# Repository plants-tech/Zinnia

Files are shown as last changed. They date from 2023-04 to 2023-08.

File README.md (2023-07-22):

# ZinniaGCC

fork of a fork of phob 2.x (Phob 2.x Official -> PhloraGCC -> ZinniaGCC)

RIP Jack Plants 

## Changes

* USB D+/D- Pad Alignment with [Model U GCC v2](https://github.com/plants-tech/Model-U-GCC-V2)
* Left Z implementation via its own pin; GPIO12
* Start Pad edit; now in style of D-Pad 
* B3f tactile switch thru-holes on ABXY pads
* Omron D2LS alignment thru-holes on ABXY pads (experimental)
* Revision of both Analog and C-Stick footprints; removal of t1/t2 thru-holes, conversion of t3 screw-holes from copper-lined pads to non-conductive thru-holes (screws work more effectively, stickbox "wobble" eliminated slightly)

## Images

### Front
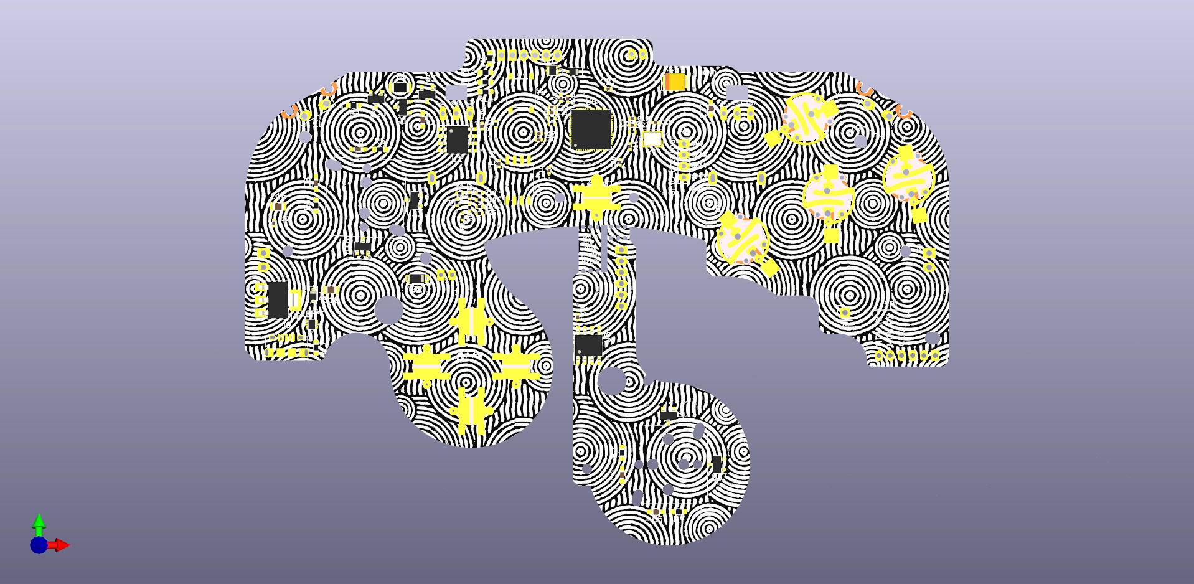
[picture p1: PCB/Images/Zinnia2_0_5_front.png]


### Back
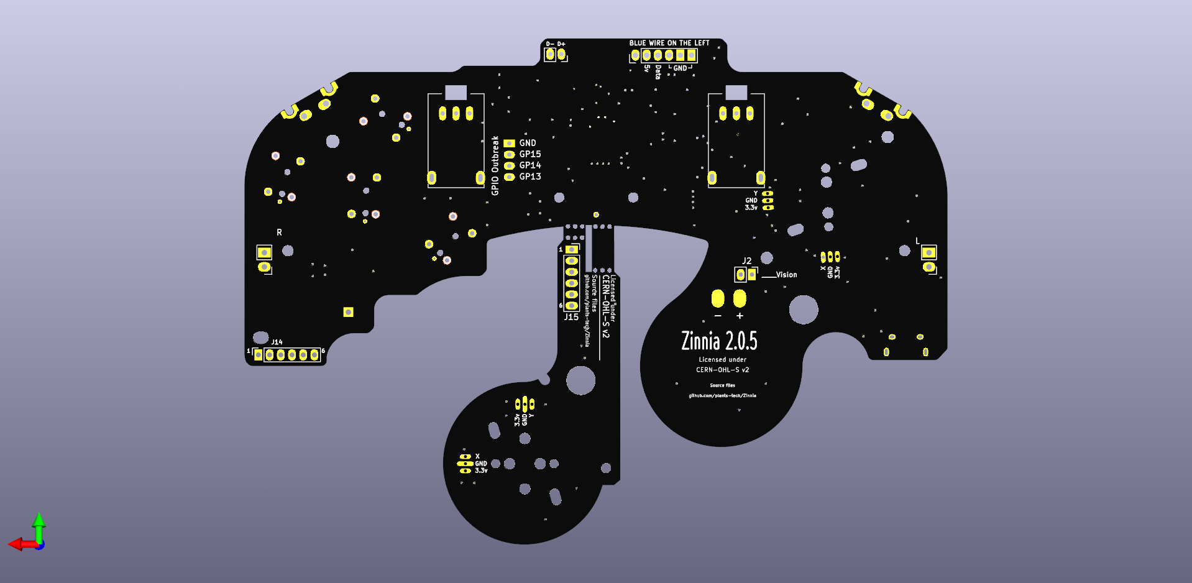
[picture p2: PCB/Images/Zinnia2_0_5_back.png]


## License

[CERN_OHL_S_v2](https://ohwr.org/cern_ohl_s_v2.txt)

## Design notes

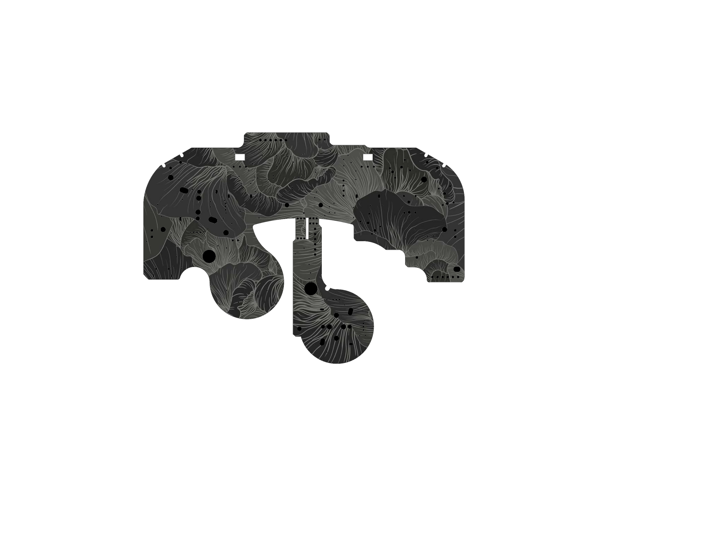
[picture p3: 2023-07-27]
PCB/Images/flower.png

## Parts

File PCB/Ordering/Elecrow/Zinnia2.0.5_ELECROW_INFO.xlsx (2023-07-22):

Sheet: PCB Specification
Your PCB Specification
PCB Quantity | 5pcs
Layer | 2layer
PCB Thickness | 1.6mm
Dimensions | 126mm*90.5mm
Castellated Hole | No
PCB Color | Black
Surface Finish | Immersion Gold
Copper Weight | 1oz
Text Color | White
Different Design | 2
Please find more PCB information on our on-line PCB ordering Page
https://www.elecrow.com/pcb-manufacturing.html

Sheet: BOM
PhobGCC v2.0.5
# | Reference | QTY | Value | Package | Manufacturer Part number | Description | SMD | THT | Original | Elecrow PN | Note
1 | R20, R21 | 2 | 27Ω | 0402 |  | Resistor | 4 |  | N
2 | R11, R12 | 2 | 100Ω | 0603 |  | Resistor | 4 |  | N
3 | R1, R2, R7, R8, R9 | 5 | 180Ω | 0402 |  | Resistor | 10 |  | N
4 | R10, R19, R24, R25 | 4 | 316Ω | 0402 |  | Resistor | 8 |  | N
5 | R16, R18 | 2 | 1kΩ | 0402 |  | Resistor | 4 |  | N
6 | R3, R4, R5, R6 | 4 | 2kΩ | 0603 |  | Resistor | 8 |  | N
7 | R13, R14, R15 | 3 | 10kΩ | 0603 |  | Resistor | 6 |  | N
8 | R17 | 1 | 100kΩ | 0603 |  | Resistor | 2 |  | N
9 | C1 | 1 | 47uF | CASE-B-3528 | CA45-B-16V-47uF-K | Capacitor | 2 |  | Y
10 | C14, C15 | 2 | 27pF | 0402 |  | Capacitor | 4 |  | N
11 | C3, C4, C5, C6, C7, C8 | 6 | 47nF | 0603 |  | Capacitor | 12 |  | N
12 | C17, C19, C20, C22, C24, C25, C26, C27, C28, C29, C30, C31, C32 | 13 | 100nF | 0402 |  | Capacitor | 26 |  | N
13 | C21, C23 | 2 | 1uF | 0402 |  | Capacitor | 4 |  | N
14 | C16, C18 | 2 | 10uF | 0805 |  | Capacitor | 4 |  | N
15 | U1, U3 | 2 |  | SOP-8 | MCP3202-CI/SN | ADC | 16 |  | Y
16 | U4, U9, U10, U11 | 4 |  | SOT-23 | DRV5055A2xDBZxQ1 | Hall Sensor | 12 |  | Y
17 | U6 | 1 |  | SOT-223-3 | AMS1117-3.3 | Voltage Regulator | 4 |  | Y
18 | U7 | 1 |  | SOIC-8-208mil | W25Q128JVSIQ | 128Mb Flash | 8 |  | Y
19 | U8 | 1 |  | LQFN-56(7x7) | RP2040 | MCU | 57 |  | Y
20 | U12, U13 | 2 |  | SOT-666-6 | USBLC6-2P6 | ESD Protection Chip | 12 |  | Y
21 | D1, D5 | 2 |  | SOD-323 | CUS10S30,H3F | Schottky Barrier Diode | 4 |  | Y
22 | D2 | 1 |  | SOD-123 | B5819W SL | Schottky Barrier Diode | 2 |  | Y
23 | Q1, Q3 | 2 |  | SOT-23-3L | AO3400A | N-Channel MOSFET | 6 |  | Y
24 | Q2 | 1 |  | SOT-23-3L | AO3401A | P-Channel MOSFET | 3 |  | Y
25 | S1 | 1 |  | SMD | TS-1187A-B-A-B | Golden Round Button | 4 |  | Y
26 | Y1 | 1 |  | SMD3225-4P | TAXM12M4RKDCDT2T | SMD Crystal Oscillator | 4 |  | Y
27 | F1 | 1 |  | 1206 | nSMD020-30V | Resettable Fuse | 2 |  | Y
28 | J8 | 1 |  | SMD | 10118194-0001LF | USB Micro | 9 |  | Y
29
30
 |  |  |  |  |  | total： | 241 | 0
 | Declare：
 | 1、If the component should be original like Digi-key or Mouser，the component must have complete Manufacture part number

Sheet: Position File
Designator |  | Footprint | Center-X(mm) | Center-Y(mm) | Rotation | Layer
C1 | 0.047u | C_0603_HandSoldering | 124.968 | 30.48 | 0 | top
C3 | 0.047u | C_0603_HandSoldering | 131.318 | -35.24 | 90 | top
C4 | 0.047u | C_0603_HandSoldering | 115.518 | -100.46 | -90 | top
C5 | 0.047u | C_0603_HandSoldering | 121.568 | -107.01 | 180 | top
C6 | 0.047u | C_0603_HandSoldering | 68.5 | -42.5 | 180 | top
C7 | 0.047u | C_0603_HandSoldering | 80 | -37.25 | -90 | top
C8 | 0.047u | C_0603_HandSoldering | 61 | -48.5 | 90 | top
C14 | 27p | C_0402_1005Metric | 116.9 | -42 | -90 | top
C15 | 27p | C_0402_1005Metric | 121.412 | -37.719 | 0 | top
C16 | 10u | C_0805_2012Metric | 54.295 | -52.705 | 0 | top
C17 | 100n | C_0402_1005Metric | 100.7 | -39.7 | 180 | top
C18 | 10u | C_0805_2012Metric | 63.67 | -67.54 | 0 | top
C19 | 100n | C_0402_1005Metric | 117.3 | -37 | 0 | top
C20 | 100n | C_0402_1005Metric | 100.7 | -40.8 | 180 | top
C21 | 1u | C_0402_1005Metric | 103 | -36 | 180 | top
C22 | 100n | C_0402_1005Metric | 117.3 | -38.2 | 0 | top
C23 | 1u | C_0402_1005Metric | 103 | -35 | 180 | top
C24 | 100n | C_0402_1005Metric | 102.5 | -46.25 | -90 | top
C25 | 100n | C_0402_1005Metric | 115.1 | -44.82 | -90 | top
C26 | 100n | C_0402_1005Metric | 105.8 | -33.528 | 90 | top
C27 | 100n | C_0402_1005Metric | 113.03 | -31.75 | 0 | top
C28 | 100n | C_0402_1005Metric | 104.6 | -33.401 | 90 | top
C29 | 100n | C_0402_1005Metric | 53.5 | -55.626 | -90 | top
C30 | 100n | C_0402_1005Metric | 90.551 | -38.354 | 90 | top
C31 | 100n | C_0402_1005Metric | 93.599 | -45.085 | -90 | top
C32 | 100n | C_0402_1005Metric | 107.5944 | -72.3646 | 90 | top
D1 | CUS10S30,H3F | D_SOD-323 | 60.46 | -68.4925 | -90 | top
D2 | M7C | D_SOD-123 | 79 | -65.51 | 180 | top
D5 | CUS10S30,H3F | D_SOD-323 | 106.934 | -28.702 | 180 | top
F1 | Fuse | Fuse_1206_3216Metric | 76 | -31.5 | 0 | top
J8 | USB_B_Micro | USB_Micro-B_Amphenol_10118194_Horizontal | 55.74 | -77.39 | 0 | top
Q1 | Q_NMOS_GSD | SOT-23 | 76.5 | -35 | 180 | top
Q2 | Q_PMOS_GDS | SOT-23 | 71.7 | -33.6 | -90 | top
Q3 | Q_NMOS_GSD | SOT-23 | 80.79 | -32.75 | -90 | top
R1 | 180 | R_0402_1005Metric | 86.106 | -52 | -90 | top
R2 | 180 | R_0402_1005Metric | 86.606 | -50.3 | 180 | top
R3 | 2k | R_0603_1608Metric_Pad0.98x0.95mm_HandSolder | 115.518 | -96.51 | 90 | top
R4 | 2k | R_0603_1608Metric_Pad0.98x0.95mm_HandSolder | 125.6055 | -107.01 | 0 | top
R5 | 2k | R_0603_1608Metric_Pad0.98x0.95mm_HandSolder | 72.4125 | -42.5 | 0 | top
R6 | 2k | R_0603_1608Metric_Pad0.98x0.95mm_HandSolder | 61 | -52.5 | -90 | top
R7 | 180 | R_0402_1005Metric | 88.356 | -50.8 | 90 | top
R8 | 180 | R_0402_1005Metric | 88.356 | -52.9 | 90 | top
R9 | 180 | R_0402_1005Metric | 87.056 | -54.5 | 90 | top
R10 | 316 | R_0402_1005Metric | 90.106 | -50.3 | 0 | top
R11 | 100R | R_0603_1608Metric_Pad0.98x0.95mm_HandSolder | 91.19 | -28.83 | 180 | top
R12 | 100R | R_0603_1608Metric_Pad0.98x0.95mm_HandSolder | 91.186 | -30.53 | 180 | top
R13 | 10k | R_0603_1608Metric_Pad0.98x0.95mm_HandSolder | 67.7 | -34.7 | 180 | top
R14 | 10k | R_0603_1608Metric_Pad0.98x0.95mm_HandSolder | 91.19 | -32.23 | 0 | top
R15 | 10k | R_0603_1608Metric_Pad0.98x0.95mm_HandSolder | 91.9 | -26.3 | -90 | top
R16 | 1k | R_0402_1005Metric | 93 | -38 | 90 | top
R17 | 100k | R_0603_1608Metric_Pad0.98x0.95mm_HandSolder | 61.02 | -77.78 | 90 | top
R18 | 1k | R_0402_1005Metric | 117.3 | -39.4 | 0 | top
R19 | 316 | R_0402_1005Metric | 90.106 | -51.5 | 0 | top
R20 | 27 | R_0402_1005Metric | 103 | -38 | 0 | top
R21 | 27 | R_0402_1005Metric | 103 | -37 | 0 | top
R24 | 316 | R_0402_1005Metric | 90.106 | -52.7 | 0 | top
R25 | 316 | R_0402_1005Metric | 90.106 | -53.9 | 0 | top
S1 | BOOTSEL | SW_TS-1187A-B-A-B | 97.5 | -32.1625 | -90 | top
U1 | MCP3002 | SOIC-8_3.9x4.9mm_P1.27mm | 86.2 | -40.8 | 0 | top
U3 | MCP3002 | SOIC-8_3.9x4.9mm_P1.27mm | 109.518 | -77.41 | 90 | top
U4 | DRV5055A2xDBZxQ1 | SOT-23 | 123.716 | -89.91 | -90 | top
U6 | AMS1117-3.3 | SOT-223-3_TabPin2 | 54.26 | -69.34 | 0 | top
U7 | W25Q128JVS | SOIC-8_5.23x5.23mm_P1.27mm | 97 | -48 | 90 | top
U8 | RP2040 | RP2040-QFN-56 | 110 | -39 | 90 | top
U9 | DRV5055A2xDBZxQ1 | SOT-23 | 132.418 | -98.61 | 180 | top
U10 | DRV5055A2xDBZxQ1 | SOT-23 | 69.350935 | -59.811215 | 87 | top
U11 | DRV5055A2xDBZxQ1 | SOT-23 | 78.475 | -51.575 | 177 | top
U12 | USBLC6-2P6 | SOT-666 | 60.26 | -73.65 | 0 | top
U13 | USBLC6-2P6 | SOT-666 | 103.124 | -28.44 | 0 | top
Y1 | Crystal_GND24 | Crystal_SMD_3225-4Pin_3.2x2.5mm | 120.9 | -40.65 | 180 | top

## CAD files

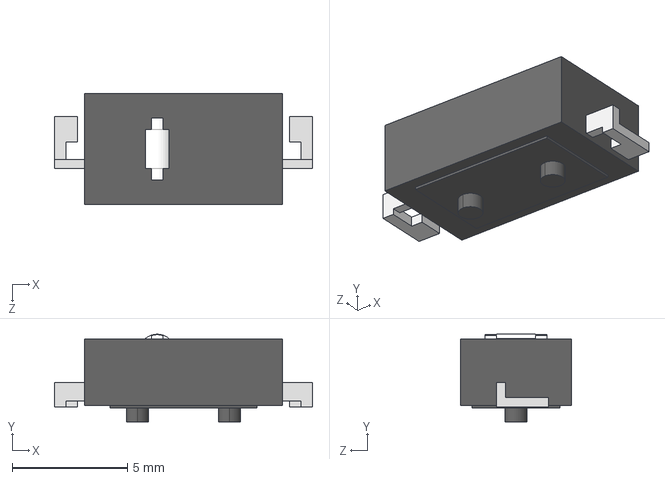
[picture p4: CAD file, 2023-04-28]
PCB/Models and Such/d2ls11.models/D2LS_11.step
11.2 x 3.80 x 4.80 mm
D2LS_11_BUTTON
D2LS_11_BASE

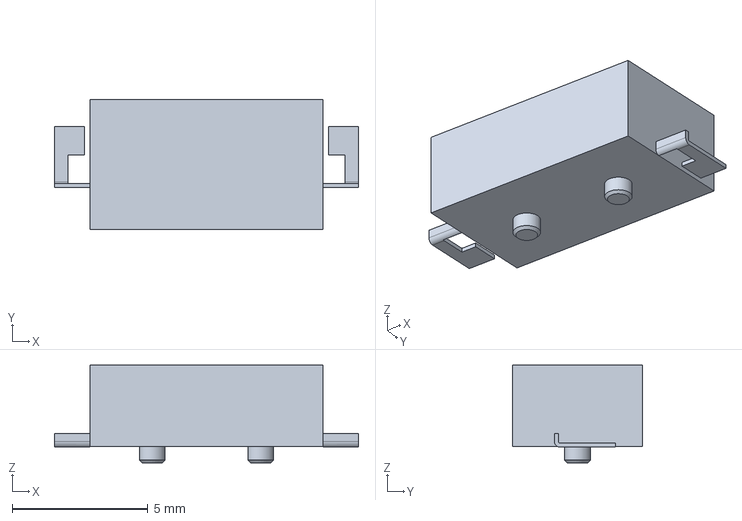
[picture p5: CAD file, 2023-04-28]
PCB/Models and Such/d2ls11.models/Omron_-_D2LS-11.step
11.2 x 4.80 x 3.60 mm

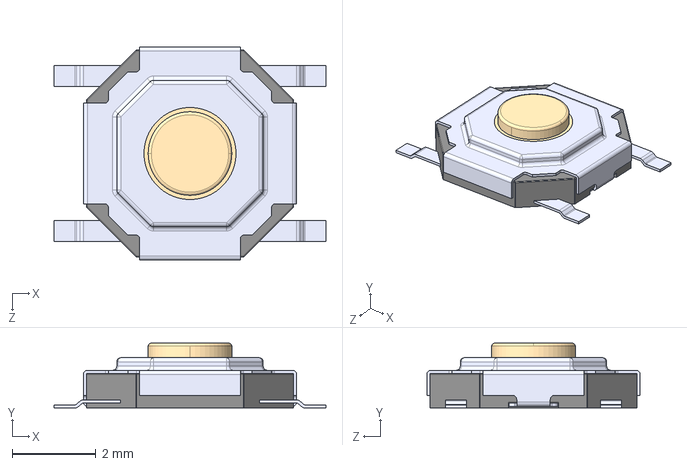
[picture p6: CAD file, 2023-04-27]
PCB/Models and Such/TS-1187A-B-A-B--3DModel-STEP-56544.STEP
6.50 x 1.55 x 5.10 mm

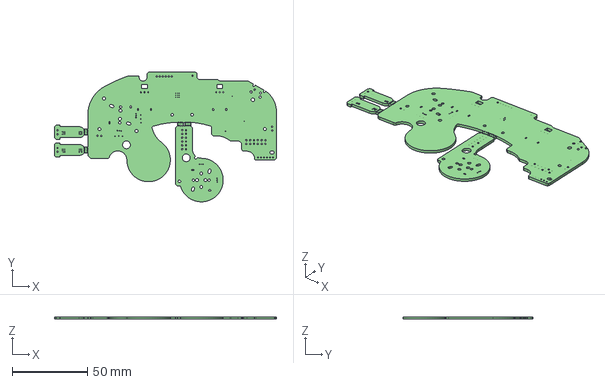
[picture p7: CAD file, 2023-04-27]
PCB/Models and Such/PhobGCC_test.step
147.6 x 86.2 x 1.60 mm

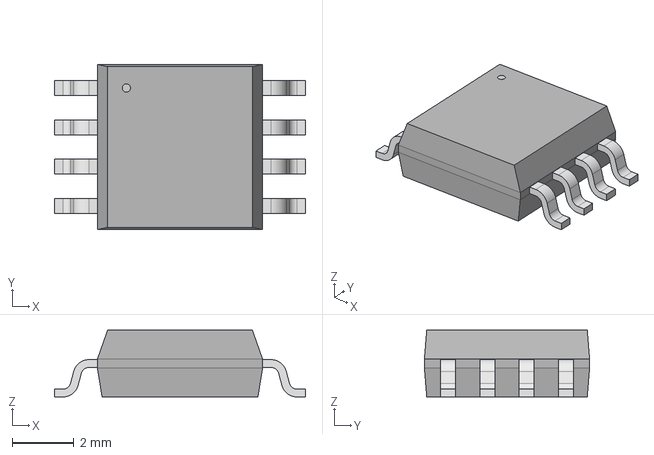
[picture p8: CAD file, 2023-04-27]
PCB/Models and Such/SOIC_128JVSIQ_WIN.step
8.10 x 5.33 x 2.16 mm

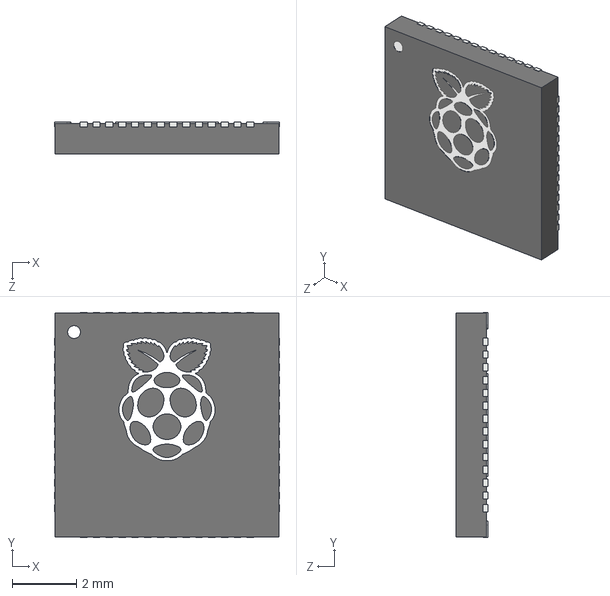
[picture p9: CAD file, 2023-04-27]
PCB/Models and Such/RP2040_QFN_PACKAGE.STEP
7.02 x 7.02 x 1.00 mm

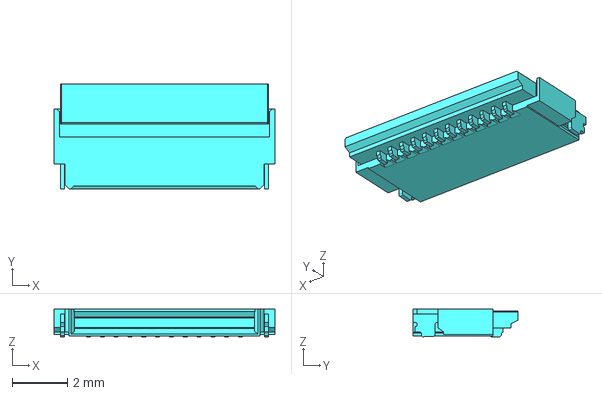
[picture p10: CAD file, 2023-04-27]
PCB/Models and Such/FH34SRJ-12S-0.5SH.stp
8.00 x 3.80 x 1.00 mm

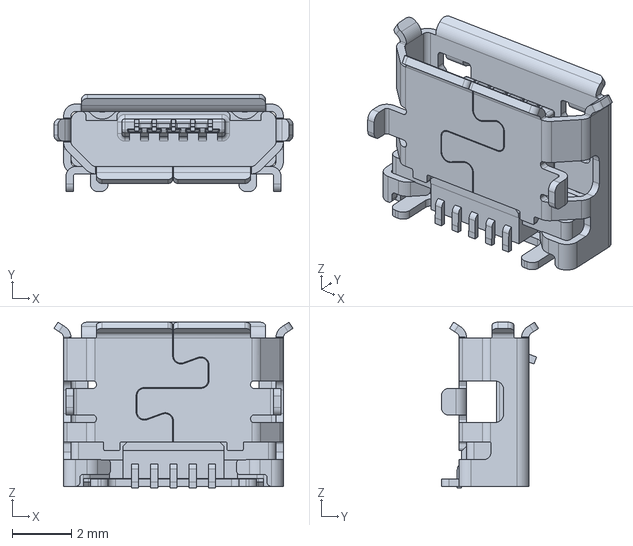
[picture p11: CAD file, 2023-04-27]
PCB/Models and Such/10118194c.stp
8.05 x 3.27 x 5.58 mm

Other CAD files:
PCB/Models and Such/10118194C.igs
PCB/Models and Such/FH34SRJ-12S-0.5SH.igs

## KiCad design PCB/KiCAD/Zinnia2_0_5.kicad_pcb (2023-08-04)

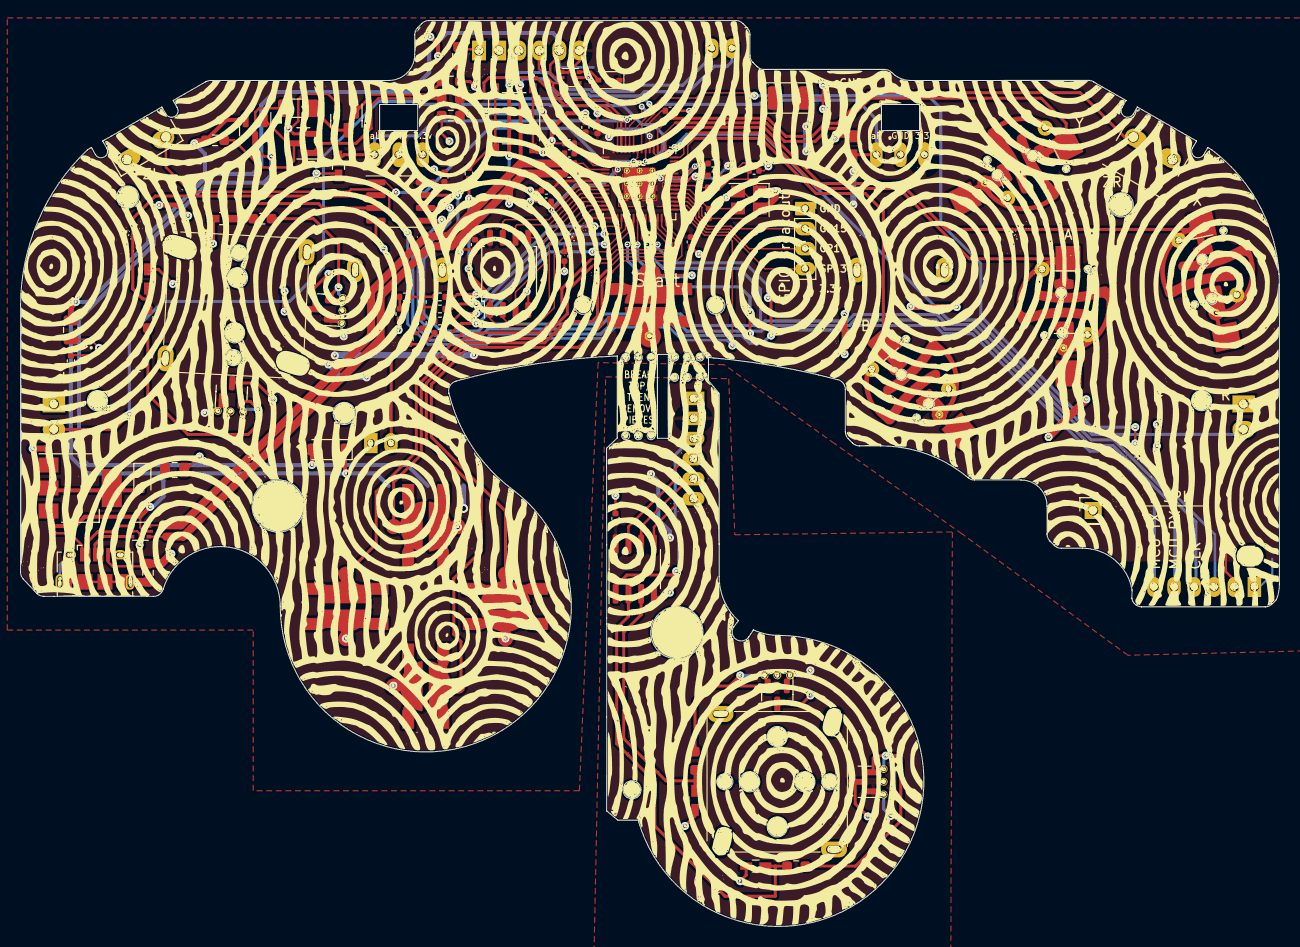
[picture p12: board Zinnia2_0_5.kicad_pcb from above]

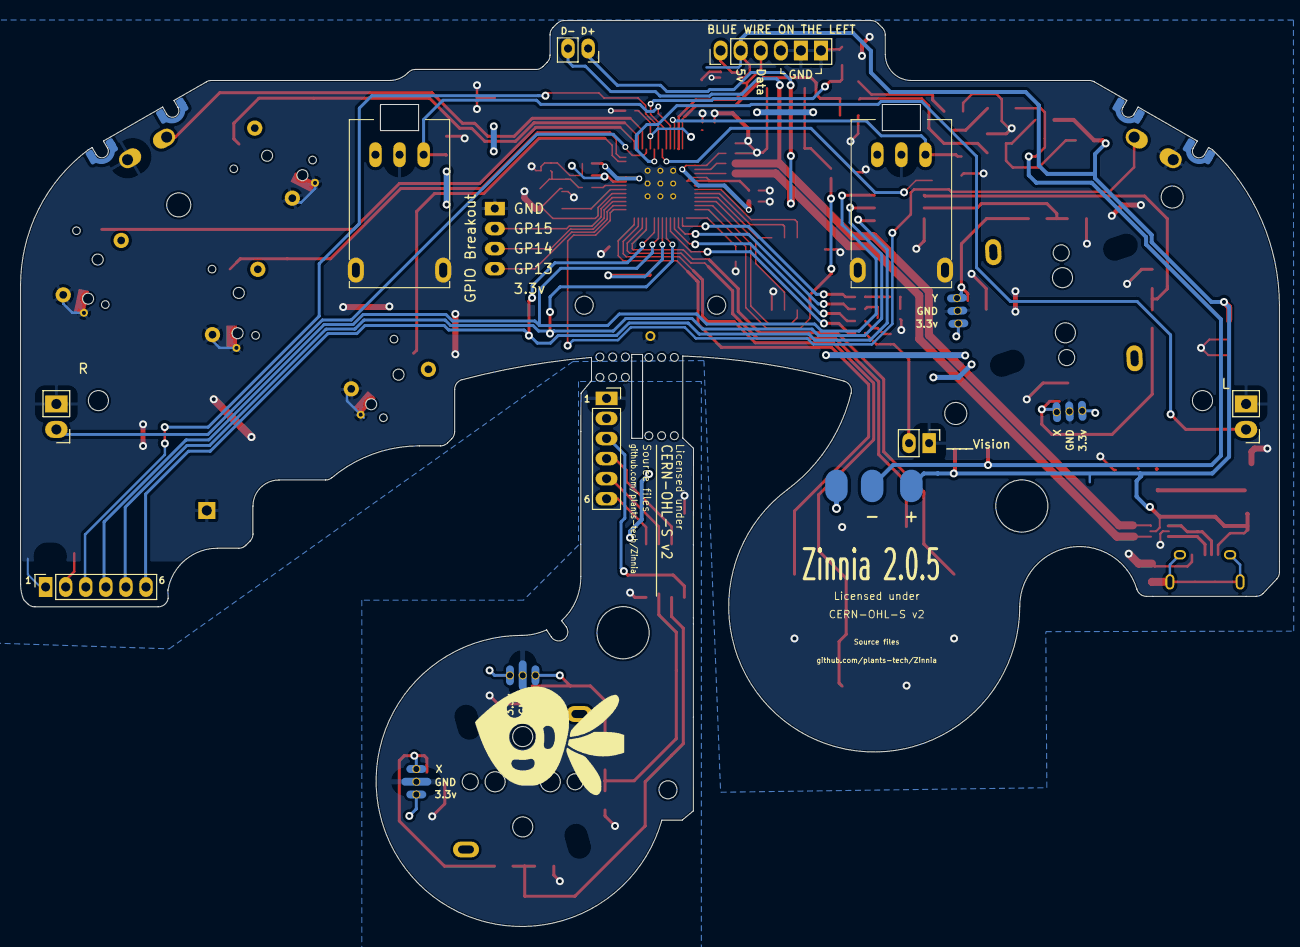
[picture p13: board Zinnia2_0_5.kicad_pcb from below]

Board: 2 copper layers, 125.4 x 90.3 mm, 110 parts (9 on the bottom side), 77 nets.

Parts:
C1: 47u; CP_EIA-3528-12_Kemet-T
C3, C4, C5, C6, C7, C8: 0.047u; C_0603_HandSoldering
C14, C15: 27p; C_0402_1005Metric
C16, C18: 10u; C_0805_2012Metric
C17, C19, C20, C22, C24, C25, C26, C27, C28, C29, C30, C31, C32: 100n; C_0402_1005Metric
C21, C23: 1u; C_0402_1005Metric
D1, D5: CUS10S30,H3F; D_SOD-323
D2: M7C; D_SOD-123
F1: Fuse; Fuse_1206_3216Metric
H1: 5.2mm; MountingHole_5.2mm
H2: Slot
H3, H4: 2mm; MountingHole_2.0mm
H5, H6: 1.8mm; MountingHole_1.8mm
H7: 2.4mm; MountingHole_2.4mm
H8, H9: 2.2mm; MountingHole_2.2mm
H10: MountingHole; MountingHole_1.8mm
H11: MountingHole; MountingHole_5.2mm
H12, H13: MountingHole; MountingHole_2.0mm
H14: MouseBite; breakaway-mousebites-double-v2-small
H15: MouseBite; breakaway-mousebites-double-v2-large
J1: Conn_01x06_Female; GCC_Header_Straight_1x06_Pitch2.00mm
J2, J11: Conn_01x02; PinHeader_1x02_P2.00mm_Vertical
J4: Conn_01x01; PinHeader_1x01_P2.54mm_Vertical
J5: Rumble; rumble_pins
J6: PinSocket_1x04_P2.00mm_Vertical
J9: USB_B_Micro; USB_Micro-B_Amphenol_10118194_Horizontal
J14, J15: Conn_01x06; PinSocket_1x06_P2.00mm_Vertical
Q1, Q3: Q_NMOS_GSD; SOT-23
Q2: Q_PMOS_GDS; SOT-23
R1, R2, R7, R8, R9: 180; R_0402_1005Metric
R3, R4, R5, R6: 2k; R_0603_1608Metric_Pad0.98x0.95mm_HandSolder
R10, R19, R24, R25: 316; R_0402_1005Metric
R11, R12: 100R; R_0603_1608Metric_Pad0.98x0.95mm_HandSolder
R13, R14, R15: 10k; R_0603_1608Metric_Pad0.98x0.95mm_HandSolder
R16, R18: 1k; R_0402_1005Metric
R17: 100k; R_0603_1608Metric_Pad0.98x0.95mm_HandSolder
R20, R21: 27; R_0402_1005Metric
RV1, RV2: R_POT_MountingPin; GCC_Slider
S1: BOOTSEL; SW_TS-1187A-B-A-B
SW1: A; ABXY_Contact_Omron_Switch_b3F
SW2: B; ABXY_Contact_Omron_Switch_b3F_v2
SW3: X; ABXY_Contact_Omron_Switch_b3F_v2
SW4: Y; ABXY_Contact_Omron_Switch_b3F_v2
SW5: Start; Dpad_Contact_TL3315NF_2
SW6: L; Pin_Header_Straight_1x02_Pitch2.54mm
SW7: R; Pin_Header_Straight_1x02_Pitch2.54mm
SW8: Z; Z_Switch_Edge_Omron
SW8L: ZL; Z_Switch_Edge_Omron
SW9: Dleft; Dpad_Contact_TL3315NF_2
SW10: Dup; Dpad_Contact_TL3315NF_2
SW11: Dright; Dpad_Contact_TL3315NF_2
SW12: Ddown; Dpad_Contact_TL3315NF_2
U1, U3: MCP3002; SOIC-8_3.9x4.9mm_P1.27mm
U2: Stickbox_Assembly_Main; GCC_Stickbox_Hall_Only
U4, U9, U10, U11: DRV5055A2xDBZxQ1; SOT-23
U5: Stickbox_Assembly_CStick; GCC_Stickbox_Hall_Only
U6: AMS1117-3.3; SOT-223-3_TabPin2
U7: W25Q128JVS; SOIC-8_5.23x5.23mm_P1.27mm
U8: RP2040; RP2040-QFN-56
U12, U13: USBLC6-2P6; SOT-666
Y1: Crystal_GND24; Crystal_SMD_3225-4Pin_3.2x2.5mm

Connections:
+1V1: C19.1, C20.1, C21.1, U8.23 (DVDD), U8.45 (VREG_VOUT), U8.50 (DVDD)
+3V3: C1.1, C17.1, C18.1, C22.1, C23.1, C24.1, C25.1, C26.1, C27.1, C28.1, C29.1, C30.1, C31.1, D1.1 (K), D5.1 (K), J1.1, J14.2, RV1.1 (V+), RV2.1 (V+), U1.8 (VDD/VREF), U2.1 (H1XV), U2.4 (H1YV), U7.8 (VCC), U8.1 (IOVDD), U8.10 (IOVDD), U8.22 (IOVDD), U8.33 (IOVDD), U8.42 (IOVDD), U8.43 (ADC_AVDD), U8.44 (VREG_IN), U8.48 (USB_VDD), U8.49 (IOVDD), U10.1 (VCC), U11.1 (VCC), U13.4
+5V: C16.1, D2.1 (K), J1.2, J5.1, J9.1, Q2.2 (S), R13.2, U6.3 (VI), U12.5, U13.5
/A: SW1.1, U8.28 (GPIO17)
/B: SW2.1, U8.27 (GPIO16)
/Brake: R12.1, R14.2, U8.41 (GPIO29_ADC3)
/CLK: J14.4, U1.7 (CLK), U8.8 (GPIO6)
/CLK2: J15.4, U3.7 (CLK)
/CS1: U1.1 (~CS/SHDN), U8.36 (GPIO24)
/CS2: J14.3, U8.35 (GPIO23)
/CS2_2: J15.3, U3.1 (~CS/SHDN)
/C_x_filt: C5.1, R4.1, U3.2 (CH0)
/C_y_filt: C4.1, R3.1, U3.3 (CH1)
/Ddown: SW12.1, U8.13 (GPIO10)
/Din: J14.6, U1.5 (DIN), U8.9 (GPIO7)
/Din2: J15.6, U3.5 (DIN)
/Dleft: SW9.1, U8.11 (GPIO8)
/Dout: J14.5, U1.6 (DOUT), U8.6 (GPIO4)
/Dout2: J15.5, U3.6 (DOUT)
/Dright: SW11.1, U8.14 (GPIO11)
/Dup: SW10.1, U8.12 (GPIO9)
/GCC_DATA: J1.3, U8.40 (GPIO28_ADC2), U13.6
/GND_C: C4.2, C5.2, C32.2, J15.1, U3.4 (VSS), U4.3 (GND), U5.2 (H1XG), U5.5 (H1YG), U9.3 (GND)
/GPIO13: J6.4, U8.16 (GPIO13)
/GPIO14: J6.3, U8.17 (GPIO14)
/GPIO15: J6.2, U8.18 (GPIO15)
/H1XS: R6.2, U2.3 (H1XS), U10.2 (OUT)
/H1YS: R5.2, U2.6 (H1YS), U11.2 (OUT)
/H2XS: R4.2, U5.3 (H1XS), U9.2 (OUT)
/H2YS: R3.2, U4.2 (OUT), U5.6 (H1YS)
/L: SW6.1, U8.34 (GPIO22)
/Ladder1: R10.2, U8.2 (GPIO0)
/Ladder2: R19.2, U8.3 (GPIO1)
/Ladder3: R24.2, U8.4 (GPIO2)
/Ladder4: R25.2, U8.5 (GPIO3)
/Lanalog: C7.1, RV1.3 (Signal), U8.39 (GPIO27_ADC1)
/LeftZ: SW8L.2, U8.15 (GPIO12)
/QSPI_SCLK: U7.6 (CLK), U8.52 (QSPI_SCLK)
/QSPI_SD0: U7.5 (DI(IO0)), U8.53 (QSPI_SD0)
/QSPI_SD1: U7.2 (DO(IO1)), U8.55 (QSPI_SD1)
/QSPI_SD2: U7.3 (IO2), U8.54 (QSPI_SD2)
/QSPI_SD3: U7.7 (IO3), U8.51 (QSPI_SD3)
/QSPI_SS: R16.1, U7.1 (~CS), U8.56 (QSPI_SS)
/R: SW7.1, U8.32 (GPIO21)
/Ranalog: C3.1, RV2.3 (Signal), U8.38 (GPIO26_ADC0)
/Rumble: R11.1, R15.2, U8.37 (GPIO25)
/Start: SW5.1, U8.7 (GPIO5)
/Stick_x_filt: C8.1, R6.1, U1.2 (CH0)
/Stick_y_filt: C6.1, R5.1, U1.3 (CH1)
/USB_D+: J11.1, R20.1, U12.4
/USB_D-: J11.2, R21.1, U12.6
/V: J2.2, R9.1, R25.1
/X: SW3.1, U8.29 (GPIO18)
/XIN: C14.1, U8.20 (XIN), Y1.3
/XOUT: R18.1, U8.21 (XOUT)
/Y: SW4.1, U8.30 (GPIO19)
/Z: SW8.1, U8.31 (GPIO20)
/~USB_BOOT: R16.2, S1.C, S1.D
GND: C1.2, C3.2, C6.2, C7.2, C8.2, C14.2, C15.2, C16.2, C17.2, C18.2, C19.2, C20.2, C21.2, C22.2, C23.2, C24.2, C25.2, C26.2, C27.2, C28.2, C29.2, C30.2, C31.2, J1.4, J1.5, J1.6, J2.1, J4.1, J6.1, J9.5, J14.1, Q1.2 (S), Q3.2 (S), R1.2, R14.1, R15.1, R17.2, RV1.2 (GND), RV2.2 (GND), S1.A, S1.B, SW1.2, SW2.2, SW3.2, SW4.2, SW5.2, SW5.3, SW6.2, SW7.2, SW8.2, SW8L.1, SW9.2, SW10.2, SW11.2, SW12.2, U1.4 (VSS), U2.2 (H1XG), U2.5 (H1YG), U6.1 (GND), U7.4 (GND), U8.19 (TESTEN), U8.57 (GND), U10.3 (GND), U11.3 (GND), U12.2, U13.2, Y1.2, Y1.4
unnamed: C15.1, R18.2, Y1.1
unnamed: D1.2 (A), U6.2 (VO)
unnamed: D2.2 (A), F1.1, J5.2, Q2.3 (D)
unnamed: D5.2 (A), U13.3
unnamed: F1.2, Q3.3 (D)
unnamed: J9.6, R17.1
unnamed: Q1.1 (G), R12.2
unnamed: Q1.3 (D), Q2.1 (G), R13.1
unnamed: Q3.1 (G), R11.2
unnamed: R1.1, R2.2
unnamed: R2.1, R7.2, R10.1
unnamed: R7.1, R8.2, R19.1
unnamed: R20.2, U8.47 (USB_DP)
unnamed: R21.2, U8.46 (USB_DM)
unnamed: R8.1, R9.2, R24.1
USB_D+_Raw: J9.3, U12.3
USB_D-_Raw: J9.2, U12.1
VCC: C32.1, J15.2, U3.8 (VDD/VREF), U4.1 (VCC), U5.1 (H1XV), U5.4 (H1YV), U9.1 (VCC)

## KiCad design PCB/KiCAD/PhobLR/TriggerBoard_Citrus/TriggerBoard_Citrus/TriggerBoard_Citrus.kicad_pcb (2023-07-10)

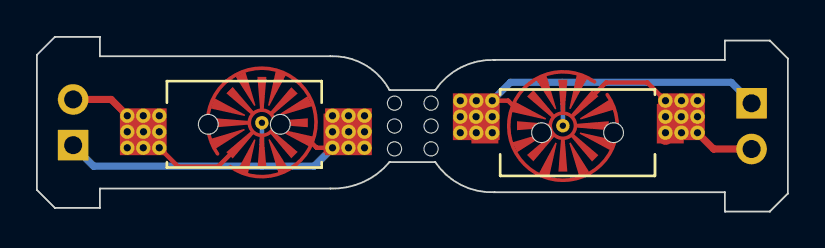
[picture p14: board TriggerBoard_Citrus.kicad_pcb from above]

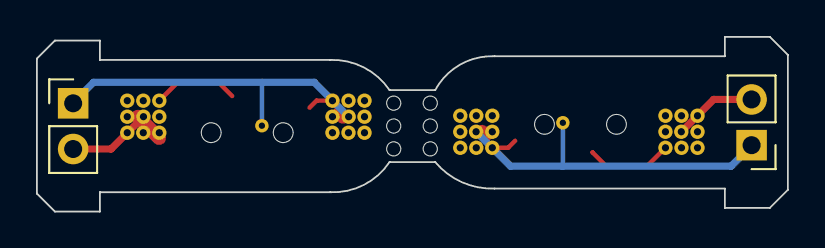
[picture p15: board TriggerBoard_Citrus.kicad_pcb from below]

Board: 2 copper layers, 41.7 x 9.7 mm, 5 parts (2 on the bottom side), 4 nets.

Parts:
H2: MouseBiteRA; breakaway-mousebites-double
J1: L; Pin_Header_Straight_1x02_Pitch2.54mm
J2: R; Pin_Header_Straight_1x02_Pitch2.54mm
SW1: L; Trigger_Contact_Big
SW2: R; Trigger_Contact_Big

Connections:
unnamed: J1.1, SW1.1
unnamed: J1.2, SW1.2
unnamed: J2.1, SW2.1
unnamed: J2.2, SW2.2

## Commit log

2023-04-27 cleaning house
    [10118194C.igs, 10118194c.stp, BOM-Zinnia2_0_5.csv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]
2023-04-27 house part 2
    cleany
    [10118194C.igs, 10118194c.stp, BOM-Zinnia2_0_5.csv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]
2023-04-28 pushy
    fixed thru holes
2023-04-28 MOUSEY THRU HOLE
    U ALREADY KNOW
    [D2LS_11.step, Omron_-_D2LS-11.step, Zinnia2_0_5.kicad_pcb]
2023-04-28 B3f pad test
    [Zinnia2_0_5.kicad_pcb]
2023-04-29 Pad Updated
    [Zinnia2_0_5.kicad_pcb]
2023-05-04 removed t2 support
    [Zinnia2_0_5.kicad_pcb]
2023-05-04 touch up/finish job on t3-screw-thru-holes
    [Zinnia2_0_5.kicad_pcb]
2023-05-22 Doing usbc stuff (unfinished)
    Removed Cfan silkscreen
    added silkscreen
    added usbc (unfinished)
    need to look for different usbc
2023-05-30 2.0.5 pcb complete
2023-05-30 2.0.5 release ready
    [BOM-Zinnia2_0_5.csv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]
2023-06-02 Updated Prod files
    Fixed D2
    [BOM-Zinnia2_0_5.csv, BOM-phlorav2_0_2.csv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]
2023-06-03 Revert "Updated Prod files"
    This reverts commit 61c3d7e021a4cafdf2df5ba8c0fc9619fe45cfe2.
    [BOM-Zinnia2_0_5.csv, BOM-phlorav2_0_2.csv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]
2023-06-03 cleaned up folders
    [BOM-Zinnia2_0_5.csv, BOM-phlorav2_0_2.csv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]
2023-06-03 revised, ready 2 go
    [BOM-Zinnia2_0_5.csv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]
2023-07-03 elecrow order info (not complete yet)
    [Zinnia2.0.5_ELECROW_INFO.xlsx]
2023-07-22 Fixed and updated
    Fixed BOM
    Fixed gerber for elecrow
    added Plant logo
    changed silkscreen for elecrow
    removed PTH for trigger mounting
    This should be the last update for now.
    [BOM-Zinnia2_0_5.csv, Zinnia2.0.5_ELECROW_INFO.xlsx, Zinnia2_0_5_7_13.csv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]
2023-07-27 Updated C16
    Double checked bom after regenerating gerbers
    moved C16 slightly to left for clearance
    [CPL-Zinnia2_0_5.csv]
2023-07-27 Added Silkscreen variant
    Added flower variant silkscreen
    [BOM-Zinnia2_0_5.csv, Zinnia2_0_5.kicad_pcb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]
2023-08-04 added 3.3v pad on back
    [Zinnia2_0_5.kicad_pcb]

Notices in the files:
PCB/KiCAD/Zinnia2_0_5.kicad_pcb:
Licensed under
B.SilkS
